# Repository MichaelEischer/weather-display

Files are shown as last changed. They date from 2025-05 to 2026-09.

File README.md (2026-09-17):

# Weather Display

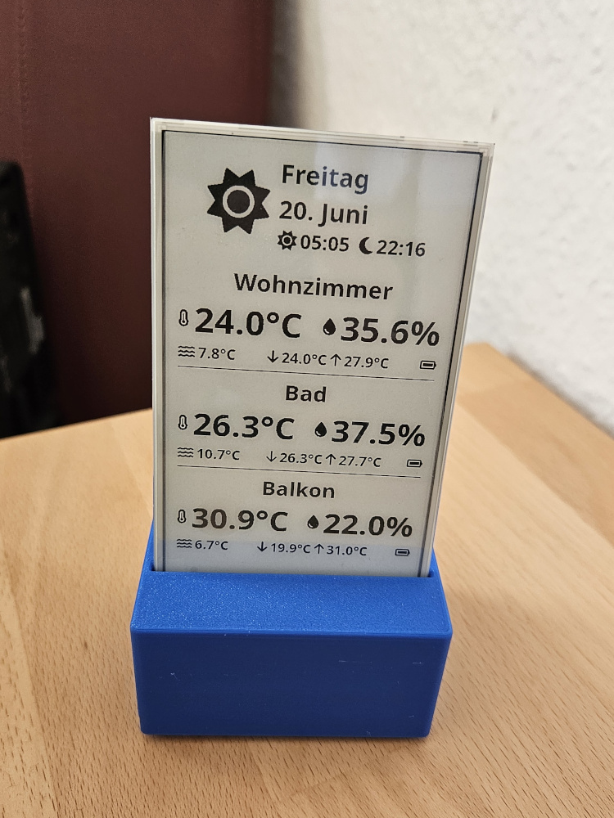
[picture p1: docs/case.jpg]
e-ink display in a 3d-printed case showing weather and temperature information


A weather display system consisting of a server component and a display component. This project allows you to display weather and temperature information on an e-ink display.

The server component connects to a Home Assistant instance and retrieves data from there. This information is used to build an SVG dashboard, which gets rendered into a portable bitmap.
The e-ink display periodically queries that dashboard and displays it.
The dashboard lists temperature sensors that are labelled with "Display" in the order of their areas.

## Part List

- Seeed Studio XIAO ESP32C6 - https://www.seeedstudio.com/Seeed-Studio-XIAO-ESP32C6-p-5884.html . Either get the version with pre-soldered pin headers or solder them on yourself. The un-soldered pack already includes the pin headers (check part list).
- Seeed Studio ePaper breakout board - https://www.seeedstudio.com/ePaper-breakout-Board-for-XIAO-V2-p-6374.html
- GooDisplay 4.26inch E-ink-Display 800x480 GDEQ0426T82 (Black/White) - https://eckstein-shop.de/GooDisplay-426inch-E-ink-Display-800x480-SPI-E-Paper-GDEQ0426T82 . This is identical to https://www.seeedstudio.com/4-26-Monochrome-SPI-ePaper-Display-p-6398.html .
- Some USB-C power supply

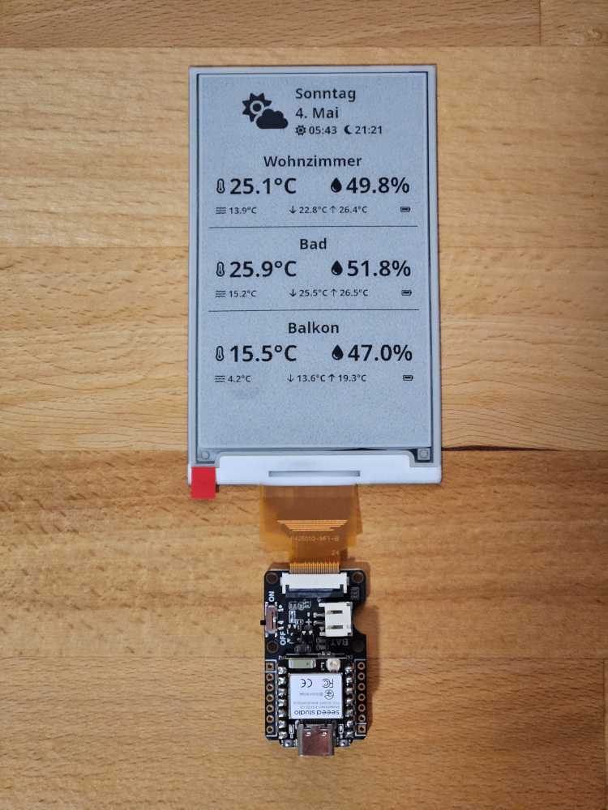
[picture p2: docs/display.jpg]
e-ink display attached to esp showing weather and temperature information


## Project Structure

- `case/` - A cardboard and a 3d-printable case for the weather display
- `display/` - Display component that shows the weather information
- `server/` - Backend server component that handles weather data processing and API integration

## Setup

### Prerequisites

- VS Code (or similar) with installed ESP-IDF 5.5.5 from https://docs.espressif.com/projects/esp-idf/en/stable/esp32/get-started/index.html#installation .
- Parts listed above
- Home Assistant installation
- Some device like a Raspberry Pi to run the server using a docker container. The guide expects that docker-compose is installed.

### Installation

1. Clone the repository:
```bash
git clone https://github.com/MichaelEischer/weather-display.git
cd weather-display
```

2. Checkout git submodules:
```bash
git submodule init
git submodule update --depth 10
```

3. Set up the server:
```bash
cd server
cp env.example .env
# Adjust .env as necessary
docker compose build
docker compose up -d
```

4. Set up the display:
```bash
cd display
# enter shell with idf.py
source "/home/michael/.espressif/tools/activate_idf_v5.5.5.sh"
# pick right target if necessary
# idf.py set-target esp32c6
idf.py build
idf.py -p /dev/ttyACM0 flash
```

## Usage

1. Start the server
2. Power on the display ESP
3. The display will show instructions how to connect it to your WiFi
4. The ESP will connect the the configured WiFi and begin showing the weather and temperature information rendered by the server

## Development

To develop using the ESP-IDF extension, you have to open ONLY the `display` subfolder of the repository! Otherwise the extension
won't work. Run the command `esp-idf: add vs code configuration folder` to generate the necessary configuration for VS code.

To develop on the `server` code, switch to the `server` folder, setup npm using `npm install` and run `npm run dev` to start the development server.
Visit http://localhost:3000/ for the SVG variant of the dashboard or go to http://localhost:3000/dashboard.png to get the image that is queried by the display.

## Contributing

Contributions are welcome! Please feel free to submit a Pull Request. However, I may be slow to respond. Expect delays of multiple weeks.

## License

This project is licensed under the GPL License - see the LICENSE file for details.

## Zigbee Repeater

Flash an esp32c6 as zigbee repeater:

```
git clone https://github.com/espressif/esp-zigbee-sdk.git
cd esp-zigbee-sdk/tree/main/examples/esp_zigbee_HA_sample/HA_color_dimmable_light
~/esp/v5.4.1/esp-idf/tools/activate.py
idf.py set-target esp32c6
idf.py -p /dev/ttyACM0 flash
```

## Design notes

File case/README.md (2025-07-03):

All case variants beneath this folder are licensed under CC BY-NC-SA 4.0. See LICENSE for details.

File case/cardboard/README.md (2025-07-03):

# Paperboard box

Use a roughly 1 mm thick cardboard. Cut it out as shown in `cardboard.svg`. Then follow the images regarding the box assembly.
Between `cardboard-3.jpg` and `cardboard-4.jpg`, assemble the ESP, display driver board and the display. Then gently push the display from inside the box through the display cutout.
Then roll the "Abstandshalter" together and place it inside the box such that it keeps the ESP from moving when plugging in the USB-C cable.
Afterwards, close the box.

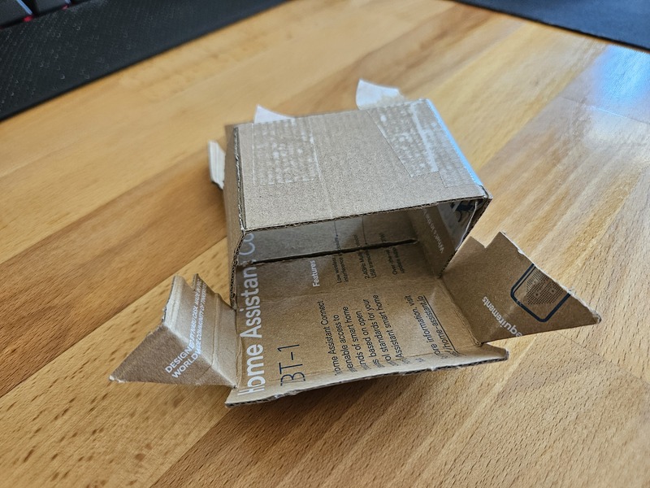
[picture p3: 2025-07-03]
case/cardboard/cardboard-1.jpg

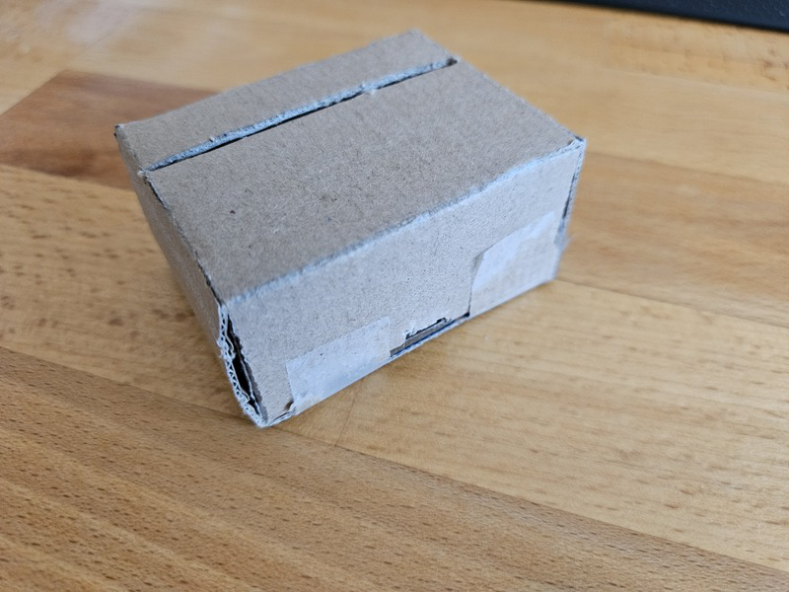
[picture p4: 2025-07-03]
case/cardboard/cardboard-4.jpg

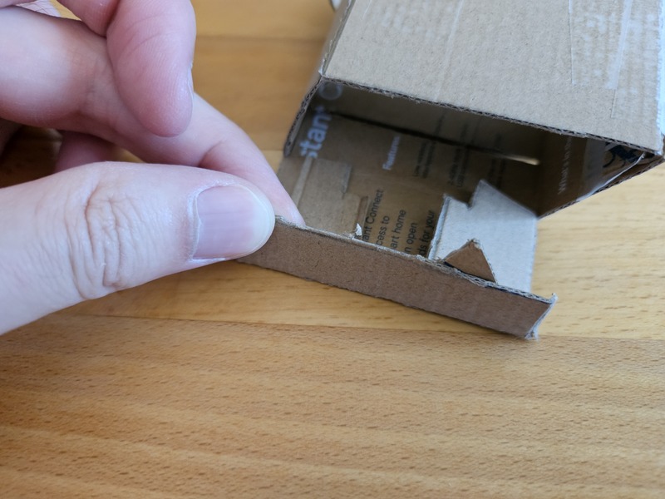
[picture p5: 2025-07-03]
case/cardboard/cardboard-2.jpg

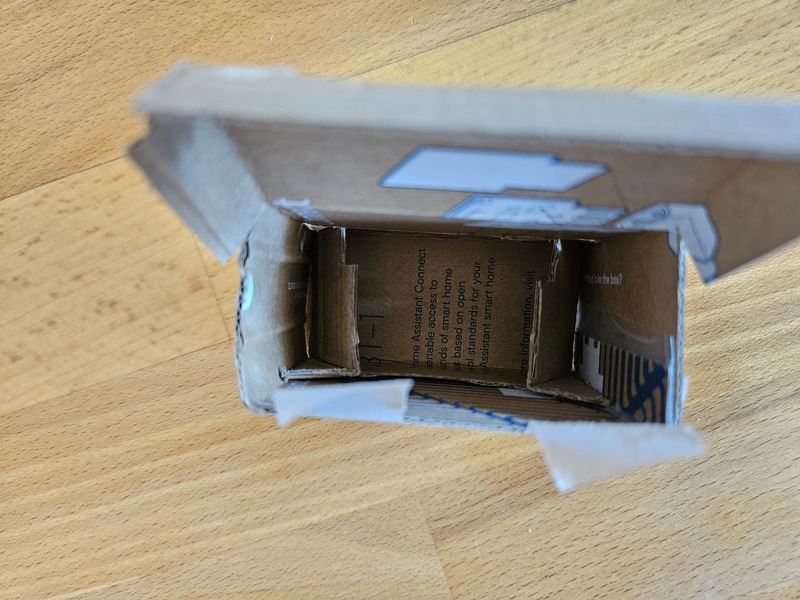
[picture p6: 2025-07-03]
case/cardboard/cardboard-3.jpg

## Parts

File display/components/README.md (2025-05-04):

# arduino-esp32

arduino-esp32 is checked out as a gitsubmodule instead of a managed component.
This is necessary as the version in the espressif registry does not include the XIAO board variants.
I found no way to reconfigure the exclusions there. Thus, just download the dependency manually.

# arduino

The CMakeLists.txt of some projects depend on a component with name `arduino` whereas others expect
`arduino-esp32`. Work around this by a stub component named `arduino` that depends on `arduino-esp32`.

# GxEPD2

The command 0x26 write to the buffer for "RED" pixel, which has no function for the B/W e-ink display.
The changes drop all corresponding code, along with using default implementations where available.
Partial refreshes of only specific display regions are not supported by the display driver. The RAM
area selection is only relevant for updating the RAM content.

Deep Sleep now uses the correct arguments according to the datasheet. A partial update now also
automatically powers down the display.

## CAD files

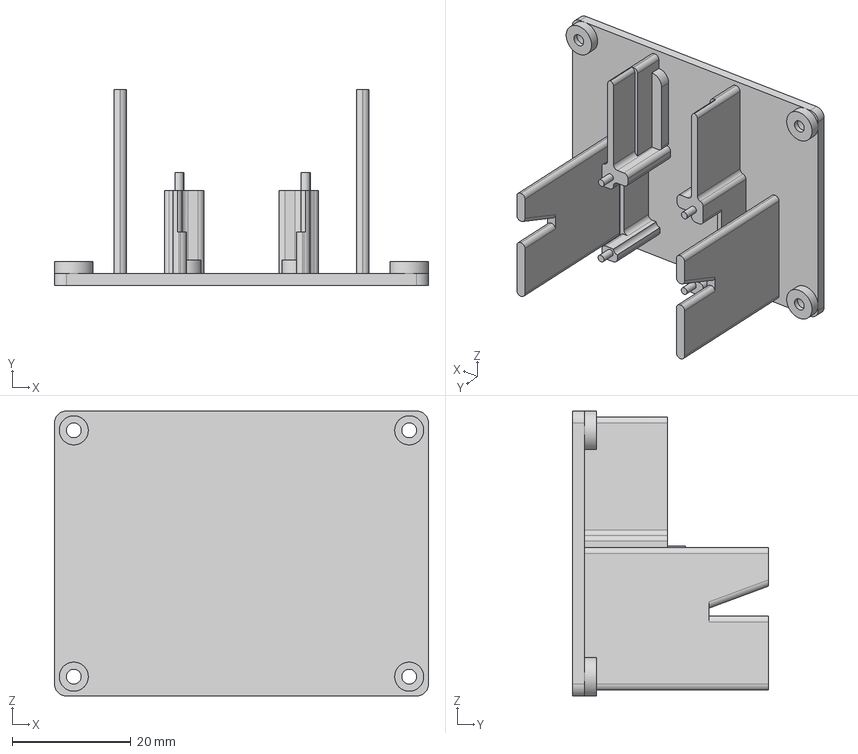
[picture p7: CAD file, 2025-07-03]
case/cad/Boden.step
63.0 x 33.0 x 48.0 mm

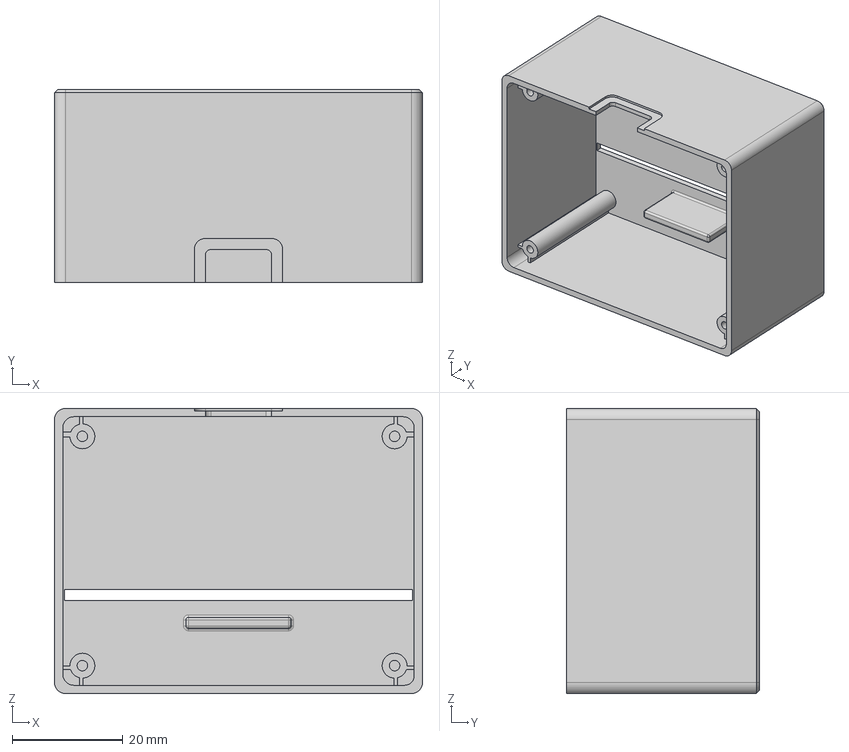
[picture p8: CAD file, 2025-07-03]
case/cad/Deckel.step
66.6 x 35.0 x 51.6 mm

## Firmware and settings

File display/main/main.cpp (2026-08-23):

#include "main.h"
#include <esp_task_wdt.h>
#include <nvs_flash.h>
#include <HTTPClient.h>
#include <SPI.h>
#include <WiFi.h>
#include <WiFiManager.h>

#include <Fonts/FreeMonoBold12pt7b.h>
#include <Fonts/FreeMonoBold18pt7b.h>

namespace WeatherDisplay {

std::string getAPName() {
    uint8_t mac[6];
    WiFi.macAddress(mac);
    char macStr[5];
    snprintf(macStr, sizeof(macStr), "%02x%02x", mac[4], mac[5]);
    return std::string(AP_NAME_BASE) + "-" + std::string(macStr);
}

WeatherDisplay& WeatherDisplay::getInstance() {
    static WeatherDisplay instance;
    return instance;
}

Error WeatherDisplay::initialize() {
    // Initialize the Task Watchdog Timer (TWDT)
    esp_task_wdt_config_t config = {
        .timeout_ms = 360000,
        .idle_core_mask = 0,
        .trigger_panic = true
    };
    ESP_ERROR_CHECK(esp_task_wdt_reconfigure(&config));
    ESP_ERROR_CHECK(esp_task_wdt_add(NULL));

    esp_pm_config_t cfg = {
        .max_freq_mhz = CONFIG_ESP_DEFAULT_CPU_FREQ_MHZ,
        .min_freq_mhz = CONFIG_XTAL_FREQ,
        .light_sleep_enable = false,
        // Enabling light sleep requires resetting the ESP using the reset+boot button
        // before flashing it.
        // .light_sleep_enable = true,
    };
    ESP_ERROR_CHECK(esp_pm_configure(&cfg));
    ESP_ERROR_CHECK(esp_pm_lock_create(ESP_PM_CPU_FREQ_MAX, 0, "dashboard", &pm_lock_));

    initEpaper();

    Error err = initNvs();
    if (err != Error::NONE) {
        return err;
    }

    err = initWifiPassword();
    if (err != Error::NONE) {
        return err;
    }

    err = initWifi();
    if (err != Error::NONE) {
        return err;
    }

    initNtp();

    // Reconfigure watchdog with shorter timeout after WiFi is connected
    config.timeout_ms = 30000;
    ESP_ERROR_CHECK(esp_task_wdt_reconfigure(&config));

    return Error::NONE;
}

void WeatherDisplay::initEpaper() {
    SPI.begin(TFT_SCLK, TFT_MISO, TFT_MOSI, -1);
    display_.epd2.selectSPI(SPI, SPISettings(SPI_FREQUENCY, MSBFIRST, TFT_SPI_MODE));
    display_.init(115200, true, 10, false);

    display_.setRotation(3);
    display_.clearScreen(GxEPD_WHITE);
    display_.fillScreen(GxEPD_WHITE);
    display_.hibernate();
}

Error WeatherDisplay::initNvs() {
    esp_err_t ret = nvs_flash_init();
    if (ret == ESP_ERR_NVS_NO_FREE_PAGES || ret == ESP_ERR_NVS_NEW_VERSION_FOUND) {
        ESP_ERROR_CHECK(nvs_flash_erase());
        ret = nvs_flash_init();
    }
    if (ret != ESP_OK) {
        displayStatus("NVS Init Failed", ret);
        return Error::NVS_INIT_FAILED;
    }
    return Error::NONE;
}

Error WeatherDisplay::initWifiPassword() {
    // Generate a static AP password such that it doesn't change on each boot

    // Try to read the AP password from NVS
    nvs_handle_t nvs_handle;
    esp_err_t ret = nvs_open("storage", NVS_READWRITE, &nvs_handle);
    if (ret != ESP_OK) {
        displayStatus("NVS Open Failed", ret);
        return Error::WIFI_PASSWORD_FAILED;
    }

    size_t required_size;
    ret = nvs_get_str(nvs_handle, "ap_password", nullptr, &required_size);
    if (ret == ESP_OK) {
        // Password exists in NVS, read it
        apPassword_.resize(required_size);
        ret = nvs_get_str(nvs_handle, "ap_password", &apPassword_[0], &required_size);
        if (ret != ESP_OK) {
            displayStatus("NVS Read Failed", ret);
            nvs_close(nvs_handle);
            return Error::WIFI_PASSWORD_FAILED;
        }
        // remove the null terminator
        apPassword_.resize(required_size - 1);
    } else if (ret == ESP_ERR_NVS_NOT_FOUND) {
        // Password doesn't exist, generate a new one
        generateApPassword();
        
        // Store the new password in NVS
        ret = nvs_set_str(nvs_handle, "ap_password", apPassword_.c_str());
        if (ret != ESP_OK) {
            displayStatus("NVS Write Failed", ret);
            nvs_close(nvs_handle);
            return Error::WIFI_PASSWORD_FAILED;
        }
        
        // Commit the changes
        ret = nvs_commit(nvs_handle);
        if (ret != ESP_OK) {
            displayStatus("NVS Commit Failed", ret);
            nvs_close(nvs_handle);
            return Error::WIFI_PASSWORD_FAILED;
        }
    } else {
        displayStatus("NVS Error", ret);
        nvs_close(nvs_handle);
        return Error::WIFI_PASSWORD_FAILED;
    }

    nvs_close(nvs_handle);
    return Error::NONE;
}

Error WeatherDisplay::initWifi() {
    displayStatus("Connecting to WiFi");
    
    WiFiManager wifiManager;
    wifiManager.setConnectRetries(3);
    wifiManager.setConfigPortalTimeout(300);
    wifiManager.setShowInfoUpdate(false);
    wifiManager.setCountry(AP_COUNTRY);
    wifiManager.setAPCallback([this](WiFiManager* wm) { this->configModeCallback(wm); });
    
    if (!wifiManager.autoConnect(getAPName().c_str(), apPassword_.c_str())) {
        displayStatus("WiFi setup failed");
        return Error::WIFI_CONNECT_FAILED;
    }

    return Error::NONE;
}

void WeatherDisplay::initNtp() {
    configTime(GMT_OFFSET_SEC, DAYLIGHT_OFFSET_SEC, NTP_SERVER1, NTP_SERVER2);
}

void WeatherDisplay::displayStatus(const std::string& status, esp_err_t err) {
    display_.setFont(&FreeMonoBold18pt7b);
    display_.setTextColor(GxEPD_BLACK);
    display_.fillScreen(GxEPD_WHITE);

    // Draw main status message
    int16_t error_y = display_.height() / 2;
    uint16_t tbh = drawCenteredText(status, error_y);

    if (err != ESP_OK) {
        char err_msg[64];
        snprintf(err_msg, sizeof(err_msg), "Error: 0x%x", err);
        error_y += tbh + 10;
        drawCenteredText(err_msg, error_y);

        error_y += tbh + 5;
        drawCenteredText(esp_err_to_name(err), error_y);
    }

    display_.display(true);
    display_.hibernate();
}

void WeatherDisplay::generateApPassword() {
    apPassword_.resize(AP_PASSWORD_LENGTH);
    for (char& c : apPassword_) {
        c = 'a' + random(26);
    }
}

uint16_t WeatherDisplay::drawCenteredText(const std::string& text, int16_t y) {
    int16_t tbx, tby;
    uint16_t tbw, tbh;

    display_.getTextBounds(text.c_str(), 0, 0, &tbx, &tby, &tbw, &tbh);
    int16_t x = (display_.width() - tbw) / 2 - tbx;
    display_.setCursor(x, y);
    display_.print(text.c_str());
    return tbh;
}

void WeatherDisplay::configModeCallback(WiFiManager* wifiManager) {
    display_.fillScreen(GxEPD_WHITE);
    display_.setFont(&FreeMonoBold18pt7b);
    display_.setTextColor(GxEPD_BLACK);

    // Calculate center positions
    int16_t center_x = display_.width() / 2;
    int16_t center_y = display_.height() / 2;

    // Draw "Scan to setup WiFi" text
    const char* title = "Scan to setup WiFi";
    int16_t title_y = 40; // Top margin
    uint16_t tbh = drawCenteredText(title, title_y);

    // Draw QR code
    std::string status = "WIFI:S:" + getAPName() + ";T:WPA;P:" + apPassword_ + ";H:false;";
    drawQrcode(status, center_x, center_y);

    display_.setFont(&FreeMonoBold12pt7b);

    // Draw AP name
    std::string ap_name = "SSID: " + getAPName();
    int16_t ap_y = center_y + 120; // Below QR code
    tbh = drawCenteredText(ap_name, ap_y);
    
    // Draw password
    std::string ap_pass = "Pass: " + apPassword_;
    ap_y += tbh + 5; // Small gap between lines
    tbh = drawCenteredText(ap_pass, ap_y);

    // Draw IP address
    const char* ip = "http://192.168.4.1";
    int16_t ip_y = ap_y + tbh + 10; // Below AP info
    tbh = drawCenteredText(ip, ip_y);

    display_.display(true);
    display_.hibernate();
}

// Initialize static members
int16_t WeatherDisplay::qrCodeX_ = 0;
int16_t WeatherDisplay::qrCodeY_ = 0;

void WeatherDisplay::displayQrcode(esp_qrcode_handle_t qrcode, int16_t x, int16_t y) {
    constexpr int border = 2;
    constexpr int pixel_size = 4;
    int size = esp_qrcode_get_size(qrcode);
    
    // Calculate the total size including border and pixel size
    int total_size = (size + 2 * border) * pixel_size;
    
    // Calculate the offset to center the QR code on the given coordinates
    int16_t offset_x = x - total_size / 2;
    int16_t offset_y = y - total_size / 2;
    
    for (int y_pos = -border; y_pos < size + border; y_pos++) {
        for (int x_pos = -border; x_pos < size + border; x_pos++) {
            uint16_t color = esp_qrcode_get_module(qrcode, x_pos, y_pos) ? GxEPD_BLACK : GxEPD_WHITE;
            display_.fillRect(x_pos * pixel_size + offset_x, y_pos * pixel_size + offset_y, 
                             pixel_size, pixel_size, color);
        }
    }
}

void WeatherDisplay::drawQrcode(const std::string& text, int16_t x, int16_t y) {
    qrCodeX_ = x;
    qrCodeY_ = y;
    
    esp_qrcode_config_t cfg = {
        .display_func = [](esp_qrcode_handle_t qrcode) {
            WeatherDisplay::getInstance().displayQrcode(qrcode, qrCodeX_, qrCodeY_);
        },
        .max_qrcode_version = 10,
        .qrcode_ecc_level = ESP_QRCODE_ECC_LOW,
    };
    esp_qrcode_generate(&cfg, text.c_str());
}

void WeatherDisplay::update() {
    // set to true to enter the fallback path if time is not available
    bool timeAvailable = true;
    time_t lastUpdate = 0;
    while (true) {
        esp_task_wdt_reset();

        struct tm timeinfo;
        if (getLocalTime(&timeinfo)) {
            timeAvailable = true;
            time_t now = mktime(&timeinfo);
            
            if (lastUpdate == 0 || (now / 60) != (lastUpdate / 60)) {
                fetchAndDisplayDashboard();
                lastUpdate = now;

                // Nightly full refresh to remove ghosting
                if (timeinfo.tm_hour == 3 && timeinfo.tm_min == 0) {
                    display_.display(false);
                    display_.hibernate();
                }
            }
            waitNextSecond();
        } else if (timeAvailable) {
            displayStatus("No time available");
            timeAvailable = false;
            delay(1000);
        }
    }
}

void WeatherDisplay::waitNextSecond() {
    struct timespec ts;
    clock_gettime(CLOCK_REALTIME, &ts);
    int toSleep = 1000 - (ts.tv_nsec / 1000000);
    delay(toSleep);
}

void WeatherDisplay::fetchAndDisplayDashboard() {
    esp_pm_lock_acquire(pm_lock_);
    String status = downloadDashboard();
    // immediate retry to not show a transient error
    if (!status.isEmpty()) {
        esp_task_wdt_reset();
        status = downloadDashboard();
    }

    if (status.isEmpty()) {
        if (checkForDashboardChange() || errorIsShown_) {
            displayDashboard();
            identicalDraws_ = 1;
        } else if (identicalDraws_ < 3) {
            // Draw the same image three times to improve contrast
            display_.display(true);
            identicalDraws_++;
        }
        downloadErrors_ = 0;
        errorIsShown_ = false;
    } else {
        if (downloadErrors_ > 5) {
            // restart ESP if downloads continue to fail
            // this is essentially a workaround in case some internal state is corrupted
            ESP.restart();
        }
        if (downloadErrors_ > 0 || downloadErrors_ == -1) {
            // only show the error message if it's the second time to not disrupt the display on transient errors
            // or immediately if the display is just starting up
            displayStatus(status.c_str());
            errorIsShown_ = true;
        }
        downloadErrors_++;
    }

    esp_pm_lock_release(pm_lock_);
}

String WeatherDisplay::downloadDashboard() {
    HTTPClient http;
    http.begin(String("http://")+DASHBOARD_SERVER+"/dashboard.pbm");
    // 10 seconds timeout. The dashboard takes roughly 1 second to render on the server.
    http.setTimeout(10000);
    
    int httpCode = http.GET();
    if (httpCode != HTTP_CODE_OK) {
        char statusMsg[64];
        if (httpCode < 0) {
            snprintf(statusMsg, sizeof(statusMsg), "Dashboard download failed: %s",
                     HTTPClient::errorToString(httpCode).c_str());
        } else {
            snprintf(statusMsg, sizeof(statusMsg), "Dashboard download failed: %d", httpCode);
        }
        http.end();
        return statusMsg;
    }

    // Read PBM header
    WiFiClient* stream = http.getStreamPtr();
    char header[64];
    size_t headerLen = stream->readBytesUntil('\n', header, sizeof(header) - 1);
    header[headerLen] = '\0';

    // Verify PBM magic number
    if (strncmp(header, "P4", 2) != 0) {
        http.end();
        return "Invalid PBM format";
    }

    // Skip comments
    while (true) {
        headerLen = stream->readBytesUntil('\n', header, sizeof(header) - 1);
        header[headerLen] = '\0';
        if (header[0] != '#') break;
    }

    // Parse dimensions
    int width, height;
    if (sscanf(header, "%d %d", &width, &height) != 2) {
        http.end();
        return "Invalid PBM dimensions";
    }

    // Verify dimensions match expected size
    if (width != display_.width() || height != display_.height()) {
        char statusMsg[64];
        snprintf(statusMsg, sizeof(statusMsg), "Invalid size: %dx%d", width, height);
        http.end();
        return statusMsg;
    }

    // PBM packs pixels row-wise, padding each row to a full byte
    size_t expectedSize = static_cast<size_t>((width + 7) / 8) * static_cast<size_t>(height);

    // Allocate buffer for the PBM data
    if (dashboardBuffer_ == nullptr || dashboardBufferSize_ < expectedSize) {
        if (dashboardBuffer_ != nullptr) {
            free(dashboardBuffer_);
        }
        dashboardBuffer_ = (uint8_t*)malloc(expectedSize);
        if (dashboardBuffer_ == nullptr) {
            http.end();
            return "Memory allocation failed";
        }
        dashboardBufferSize_ = expectedSize;
    }

    // readBytes drains the RX buffer first, then waits up to the HTTP timeout.
    size_t bytesRead = stream->readBytes(dashboardBuffer_, expectedSize);
    if (bytesRead != expectedSize) {
        const char *err = stream->connected() ? "Stream read timeout" : "Stream disconnected";
        http.end();
        return err;
    }
    http.end();
    return "";
}

bool WeatherDisplay::checkForDashboardChange() {
    // Calculate hash of the new dashboard content
    // A simple hash function is good enough
    uint32_t newHash = 0;
    for (size_t i = 0; i < dashboardBufferSize_; i++) {
        newHash = (newHash * 31) + dashboardBuffer_[i];
    }

    // Only update if the content has changed
    if (newHash != currentDashboardHash_) {
        currentDashboardHash_ = newHash;
        return true;
    }

    return false;
}

void WeatherDisplay::displayDashboard() {
    // Display the image. 1 = black, 0 = white.
    display_.fillScreen(GxEPD_WHITE);
    // only sets the pixels that have 1 in the buffer
    display_.drawBitmap(0, 0, dashboardBuffer_, display_.width(), display_.height(), GxEPD_BLACK);
    display_.display(true);
    display_.hibernate();
}
} // namespace ClockDisplay

static void fatal_error() {
    while (true) {
        delay(1000);
    }
}

extern "C" void app_main() {
    initArduino();
    auto& display = WeatherDisplay::WeatherDisplay::getInstance();
    WeatherDisplay::Error err = display.initialize();
    
    if (err != WeatherDisplay::Error::NONE) {
        fatal_error();
    }
    
    display.update();
}

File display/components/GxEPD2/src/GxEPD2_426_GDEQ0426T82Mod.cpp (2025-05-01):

// Display Library for SPI e-paper panels from Dalian Good Display and boards from Waveshare.
// Requires HW SPI and Adafruit_GFX. Caution: the e-paper panels require 3.3V supply AND data lines!
//
// based on Demo Example from Good Display, available here: https://www.good-display.com/comp/xcompanyFile/downloadNew.do?appId=24&fid=1722&id=1158
// Panel: GDEQ0426T82 : https://www.good-display.com/product/457.html
// Controller : SSD1677 : https://v4.cecdn.yun300.cn/100001_1909185148/SSD1677.pdf
//
// Author: Jean-Marc Zingg
//
// Version: see library.properties
//
// Library: https://github.com/ZinggJM/GxEPD2

#include "GxEPD2_426_GDEQ0426T82Mod.h"

GxEPD2_426_GDEQ0426T82Mod::GxEPD2_426_GDEQ0426T82Mod(int16_t cs, int16_t dc, int16_t rst, int16_t busy) :
  GxEPD2_EPD(cs, dc, rst, busy, HIGH, 10000000, WIDTH, HEIGHT, panel, hasColor, hasPartialUpdate, hasFastPartialUpdate)
{
}

void GxEPD2_426_GDEQ0426T82Mod::clearScreen(uint8_t value)
{
  _writeScreenBuffer(0x24, value);
  refresh(false); // full refresh
  _initial_write = false;
}

void GxEPD2_426_GDEQ0426T82Mod::writeScreenBuffer(uint8_t value)
{
  if (_initial_write) return clearScreen(value);
  _writeScreenBuffer(0x24, value);
}

void GxEPD2_426_GDEQ0426T82Mod::_writeScreenBuffer(uint8_t command, uint8_t value)
{
  if (!_init_display_done) _InitDisplay();
  _setPartialRamArea(0, 0, WIDTH, HEIGHT);
  _writeCommand(command);
  _startTransfer();
  for (uint32_t i = 0; i < uint32_t(WIDTH) * uint32_t(HEIGHT) / 8; i++)
  {
    _transfer(value);
  }
  _endTransfer();
}

void GxEPD2_426_GDEQ0426T82Mod::writeImage(const uint8_t bitmap[], int16_t x, int16_t y, int16_t w, int16_t h, bool invert, bool mirror_y, bool pgm)
{
  _writeImage(0x24, bitmap, x, y, w, h, invert, mirror_y, pgm);
}

void GxEPD2_426_GDEQ0426T82Mod::_writeImage(uint8_t command, const uint8_t bitmap[], int16_t x, int16_t y, int16_t w, int16_t h, bool invert, bool mirror_y, bool pgm)
{
  delay(1); // yield() to avoid WDT on ESP8266 and ESP32
  int16_t wb = (w + 7) / 8; // width bytes, bitmaps are padded
  x -= x % 8; // byte boundary
  w = wb * 8; // byte boundary
  int16_t x1 = x < 0 ? 0 : x; // limit
  int16_t y1 = y < 0 ? 0 : y; // limit
  int16_t w1 = x + w < int16_t(WIDTH) ? w : int16_t(WIDTH) - x; // limit
  int16_t h1 = y + h < int16_t(HEIGHT) ? h : int16_t(HEIGHT) - y; // limit
  int16_t dx = x1 - x;
  int16_t dy = y1 - y;
  w1 -= dx;
  h1 -= dy;
  if ((w1 <= 0) || (h1 <= 0)) return;
  if (!_init_display_done) _InitDisplay();
  if (_initial_write) writeScreenBuffer(); // initial full screen buffer clean
  _setPartialRamArea(x1, y1, w1, h1);
  _writeCommand(command);
  _startTransfer();
  for (int16_t i = 0; i < h1; i++)
  {
    for (int16_t j = 0; j < w1 / 8; j++)
    {
      uint8_t data;
      // use wb, h of bitmap for index!
      int32_t idx = mirror_y ? j + dx / 8 + ((h - 1 - int32_t(i + dy))) * wb : j + dx / 8 + int32_t(i + dy) * wb;
      if (pgm)
      {
#if defined(__AVR) || defined(ESP8266) || defined(ESP32)
        data = pgm_read_byte(&bitmap[idx]);
#else
        data = bitmap[idx];
#endif
      }
      else
      {
        data = bitmap[idx];
      }
      if (invert) data = ~data;
      _transfer(data);
    }
  }
  _endTransfer();
  delay(1); // yield() to avoid WDT on ESP8266 and ESP32
}

void GxEPD2_426_GDEQ0426T82Mod::writeImagePart(const uint8_t bitmap[], int16_t x_part, int16_t y_part, int16_t w_bitmap, int16_t h_bitmap,
    int16_t x, int16_t y, int16_t w, int16_t h, bool invert, bool mirror_y, bool pgm)
{
  _writeImagePart(0x24, bitmap, x_part, y_part, w_bitmap, h_bitmap, x, y, w, h, invert, mirror_y, pgm);
}

void GxEPD2_426_GDEQ0426T82Mod::_writeImagePart(uint8_t command, const uint8_t bitmap[], int16_t x_part, int16_t y_part, int16_t w_bitmap, int16_t h_bitmap,
    int16_t x, int16_t y, int16_t w, int16_t h, bool invert, bool mirror_y, bool pgm)
{
  delay(1); // yield() to avoid WDT on ESP8266 and ESP32
  if ((w_bitmap < 0) || (h_bitmap < 0) || (w < 0) || (h < 0)) return;
  if ((x_part < 0) || (x_part >= w_bitmap)) return;
  if ((y_part < 0) || (y_part >= h_bitmap)) return;
  int16_t wb_bitmap = (w_bitmap + 7) / 8; // width bytes, bitmaps are padded
  x_part -= x_part % 8; // byte boundary
  w = w_bitmap - x_part < w ? w_bitmap - x_part : w; // limit
  h = h_bitmap - y_part < h ? h_bitmap - y_part : h; // limit
  x -= x % 8; // byte boundary
  w = 8 * ((w + 7) / 8); // byte boundary, bitmaps are padded
  int16_t x1 = x < 0 ? 0 : x; // limit
  int16_t y1 = y < 0 ? 0 : y; // limit
  int16_t w1 = x + w < int16_t(WIDTH) ? w : int16_t(WIDTH) - x; // limit
  int16_t h1 = y + h < int16_t(HEIGHT) ? h : int16_t(HEIGHT) - y; // limit
  int16_t dx = x1 - x;
  int16_t dy = y1 - y;
  w1 -= dx;
  h1 -= dy;
  if ((w1 <= 0) || (h1 <= 0)) return;
  if (!_init_display_done) _InitDisplay();
  if (_initial_write) writeScreenBuffer(); // initial full screen buffer clean
  _setPartialRamArea(x1, y1, w1, h1);
  _writeCommand(command);
  _startTransfer();
  for (int16_t i = 0; i < h1; i++)
  {
    for (int16_t j = 0; j < w1 / 8; j++)
    {
      uint8_t data;
      // use wb_bitmap, h_bitmap of bitmap for index!
      int32_t idx = mirror_y ? x_part / 8 + j + dx / 8 + int32_t((h_bitmap - 1 - (y_part + i + dy))) * wb_bitmap : x_part / 8 + j + dx / 8 + int32_t(y_part + i + dy) * wb_bitmap;
      if (pgm)
      {
#if defined(__AVR) || defined(ESP8266) || defined(ESP32)
        data = pgm_read_byte(&bitmap[idx]);
#else
        data = bitmap[idx];
#endif
      }
      else
      {
        data = bitmap[idx];
      }
      if (invert) data = ~data;
      _transfer(data);
    }
  }
  _endTransfer();
  delay(1); // yield() to avoid WDT on ESP8266 and ESP32
}

void GxEPD2_426_GDEQ0426T82Mod::refresh(bool partial_update_mode)
{
  if (partial_update_mode) refresh(0, 0, WIDTH, HEIGHT);
  else
  {
    _Update_Full();
    _initial_refresh = false; // initial full update done
  }
}

void GxEPD2_426_GDEQ0426T82Mod::refresh(int16_t x, int16_t y, int16_t w, int16_t h)
{
  if (_initial_refresh) return refresh(false); // initial update needs be full update
  // chip always refreshes the whole screen
  _Update_Part();
}

void GxEPD2_426_GDEQ0426T82Mod::powerOff()
{
}

void GxEPD2_426_GDEQ0426T82Mod::hibernate()
{
  if (_rst >= 0)
  {
    _writeCommand(0x10); // deep sleep mode
    _writeData(0x3);     // enter deep sleep
    _hibernating = true;
    _init_display_done = false;
    // FIXME
    delay(100);
  }
}
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

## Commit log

2025-05-01 first wifi setup attempt
    [nvs_data.csv, partitions.csv]
2025-05-01 fixes and log to display
    [nvs_data.csv]
2025-05-01 cleanup initialization flow
2025-05-01 show current time after startup
2025-05-01 fix wlan init status
    [main.cpp]
2025-05-02 add fake arduino component to make packages happy
2025-05-02 fix password usage on later boot ups
    [main.cpp]
2025-05-04 show battery level
2025-05-04 add min-max temperature
2025-05-09 add missing hibernate display calls
    [main.cpp]
2025-05-10 enable esp DFS and experiment with power saving options
2025-05-11 add power lock around dashboard querying
2025-05-11 fix watchdog timer initialization
    [main.cpp]
2025-05-11 drop advanced power saving options
    something seems to cause the wifi to fail after some time
2025-05-11 restart ESP if download errors persist
    [main.cpp]
2025-05-11 refactor sensor config
2025-05-21 don't show the first download error
    [main.cpp]
2025-07-03 add case variants
    [Boden.step, Deckel.step]
2025-07-03 Add image of 3d-printed case
2026-03-28 tune battery levels
2026-03-28 auto-discover sensors
2026-03-28 order sensors according to areas in HA
2026-08-23 fix and simplify dashboard download loop
    [main.cpp]
2026-08-23 immediately retry a failed download
    [main.cpp]
2026-08-23 upgrade esp-idf to 5.5.5
    [partitions.csv]
2026-08-23 improve redraw after error
    [main.cpp]
